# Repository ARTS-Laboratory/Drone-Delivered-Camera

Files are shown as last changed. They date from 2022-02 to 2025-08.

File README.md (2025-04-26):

# Drone-Delivered-Camera
A UAV deployable camera 

<p align="center">
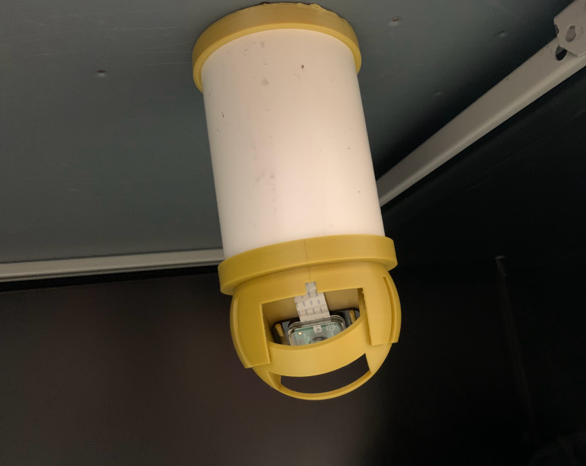
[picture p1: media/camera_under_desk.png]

</p>
<p align="center">
Figure 1: Camera Package installed underneath a structure.
</p>

## Licensing and Citation

[][cc-by-sa]

This work is licensed under a
[Creative Commons Attribution-ShareAlike 4.0 International License][cc-by-sa].

[cc-by-sa]: http://creativecommons.org/licenses/by-sa/4.0/
[cc-by-sa-image]: https://licensebuttons.net/l/by-sa/4.0/88x31.png
[cc-by-sa-shield]: https://img.shields.io/badge/License-CC%20BY--SA%204.0-lightgrey.svg

Cite as:

@Misc{ARTSLabDroneDeliveredCamera,     
  author = {{ARTS-L}ab},  
  howpublished = {GitHub},    
  title  = {Drone Delivered Camera},    
  groups = {{ARTS-L}ab},    
  url    = {https://github.com/ARTS-Laboratory/Drone-Delivered-Camera},   
}

<p align="center">
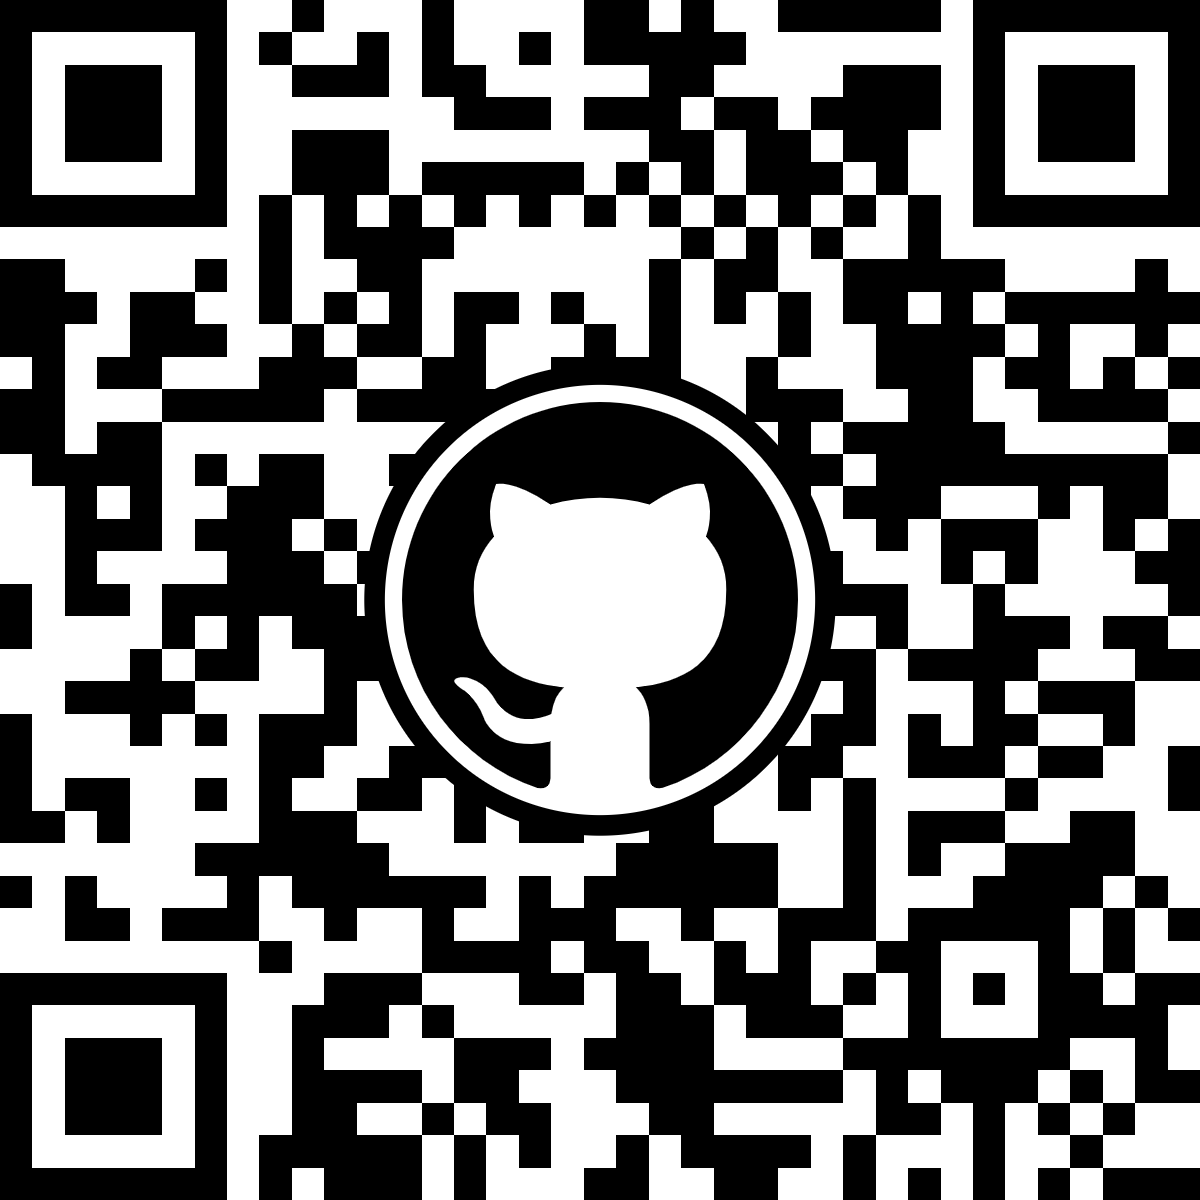
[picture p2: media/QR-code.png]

</p>
<p align="center">
QR code for repo.
</p>

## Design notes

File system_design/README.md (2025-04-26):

# System Design
The versions of the sensor package are all named after observatories.

## Palomar
....

## Rubin
....

## Lowell
....

## Keck
....

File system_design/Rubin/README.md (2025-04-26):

# Rubin

UAV deployable camera package for monitoring hydrology and performing edge computing. 
<p align="center">

</p>
<p align="center">
Figure 1: Camera Package installed underneath a structure.
</p>

## Modular Components
The major components of this package are:
1. Control Board (Raspberry Pi)
2. Camera (PiCam v2.1)
3. Electropermanent Magnet
4. Radio Chip (NRF)

## NRFCommunicate

NRFCommunicate wraps a basic NRF circuit-python package. The goal is to create a plug-and-play library not just for uploading data, but also for communication between sensor packages.

## V1
1.	Powered off battery (not battery monitoring)
1.	Begins program on startup
1.	Takes picture whenever it gets a signal from the NRF
1.	Images stored on a SD card on the PI (not sure how to extract data)
1.	Has the electro permanent magnet that can turn on and off with a signal from the NRF (need to see if we can integrates this with the controller from the gauge sensor)

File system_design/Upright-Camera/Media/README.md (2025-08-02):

File contains necessary pictures on any updated parts/software for the Fisheye Lens Upright Camera Package.

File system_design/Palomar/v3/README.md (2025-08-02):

File contains necessary information on any updated parts/software for the Palomar Camera Package.

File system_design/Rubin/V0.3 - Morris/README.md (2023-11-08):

# V0.3.0 -Morris
UAV deployable camera package for monitoring hydrology and performing edge computing.

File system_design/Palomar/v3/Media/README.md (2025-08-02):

File contains necessary Pictures on any updated parts/software for the Palomar Camera Package.

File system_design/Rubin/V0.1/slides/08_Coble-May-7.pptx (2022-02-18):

## MACHINE LEARNING DETECTION OF FOREST FIRES

Nile Coble Week 1 Review

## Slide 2

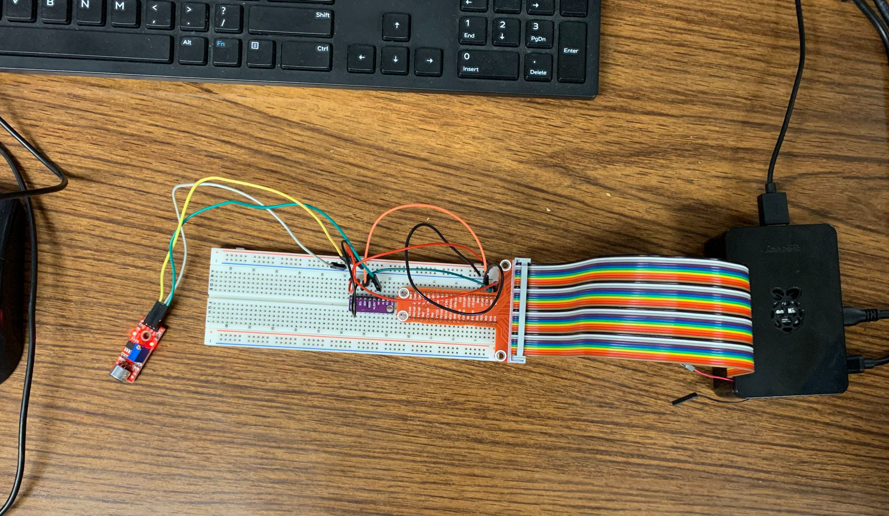
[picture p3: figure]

ADC ^

^ RPi pinout

<-- microphone

Raspberry Pi ^

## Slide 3

Current state
- Record for a given time and create a .wav file
Issues
- Aliased to below 430 Hz
- Small amount of unique mV values within range:
Min mV: 30448
Max mV: 31264
Range: 816
Unique values: 31

## THANK YOU

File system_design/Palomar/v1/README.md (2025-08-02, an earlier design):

Folder Contains necessary information regarding CAD Files, Software, and any other
items used in the construction of Palomar v1.

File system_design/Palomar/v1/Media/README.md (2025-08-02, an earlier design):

Pictures within this file showcase the first version of
the Palomar Camera Package, with a simple glued-on camera
that runs YOLOv11 through a RaspberryPi 4. Package was meant
to prototype a wireless package that could be dropped and
identify objects.

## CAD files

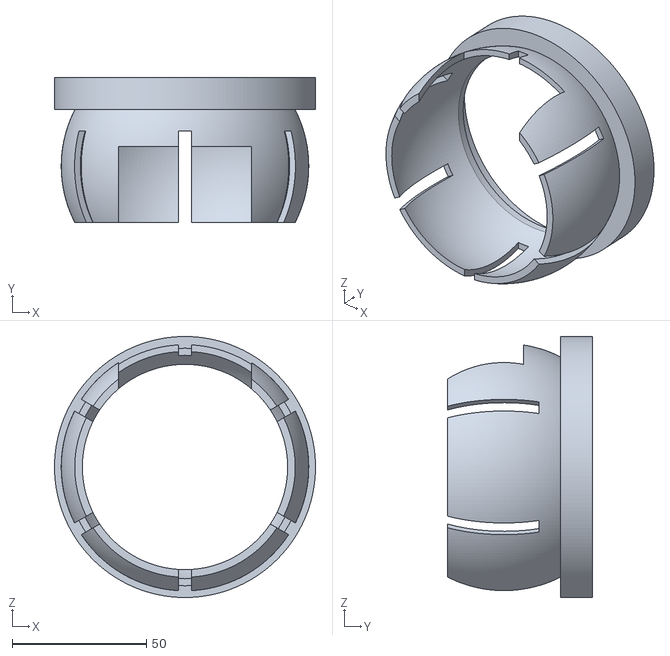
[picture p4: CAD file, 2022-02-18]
system_design/Rubin/V0.1/CAD/stl/bot-v2.stl
97.2 x 54.0 x 97.2

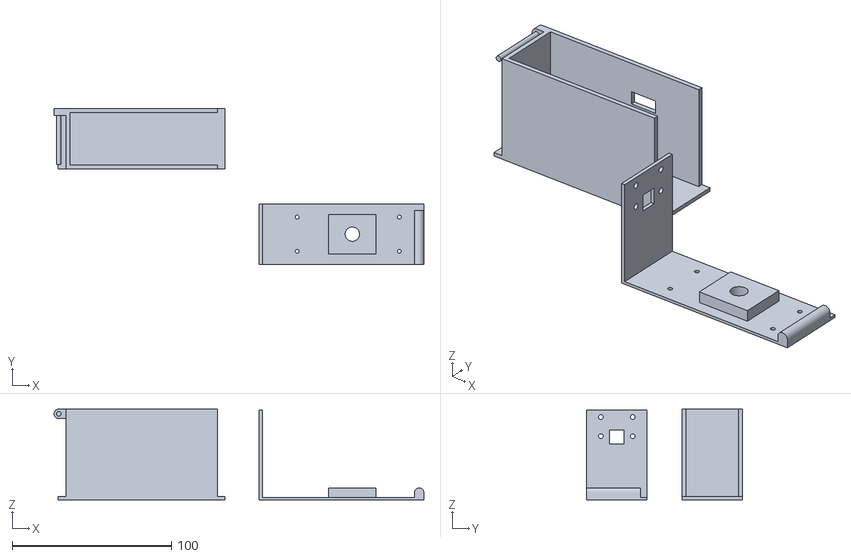
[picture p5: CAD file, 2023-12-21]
system_design/Rubin/V0.3 - Morris/Case Camera_.stl
232.3 x 97.9 x 57.0

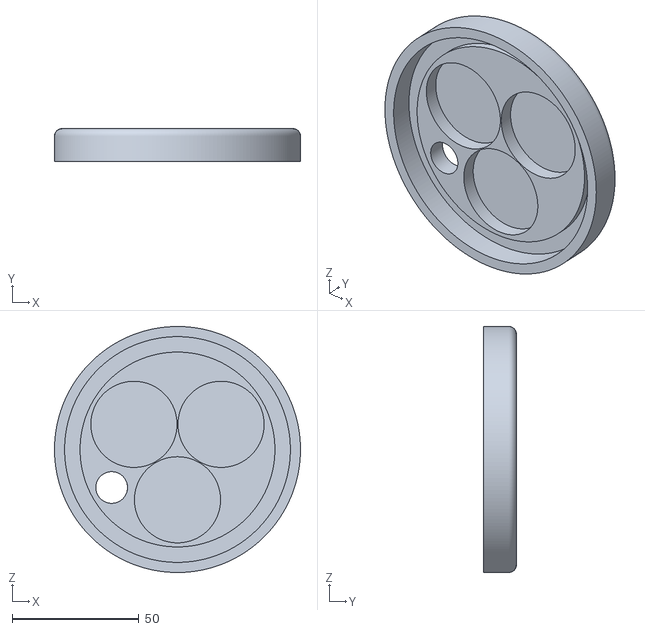
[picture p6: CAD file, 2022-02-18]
system_design/Rubin/V0.1/CAD/stl/lid-proto-v2.stl
97.1 x 13.0 x 97.1

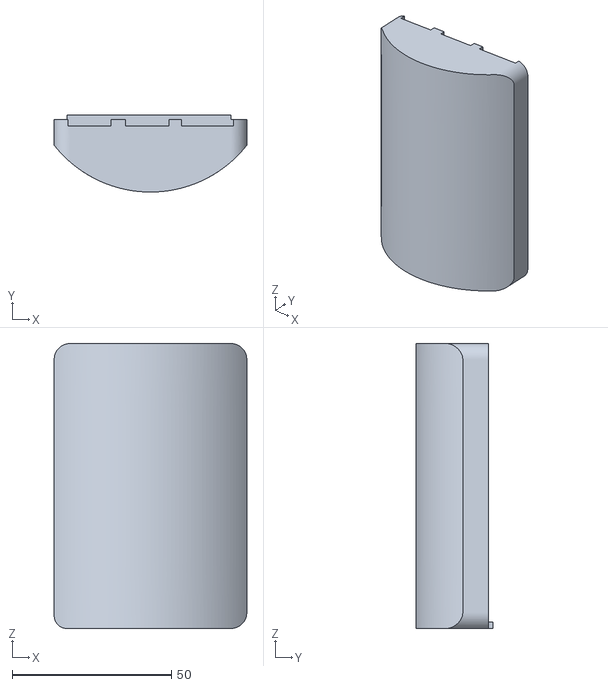
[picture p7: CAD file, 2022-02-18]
system_design/Rubin/V0.2 - Toth/CAD/stl/piholder-v5.stl
60.5 x 24.2 x 89.5

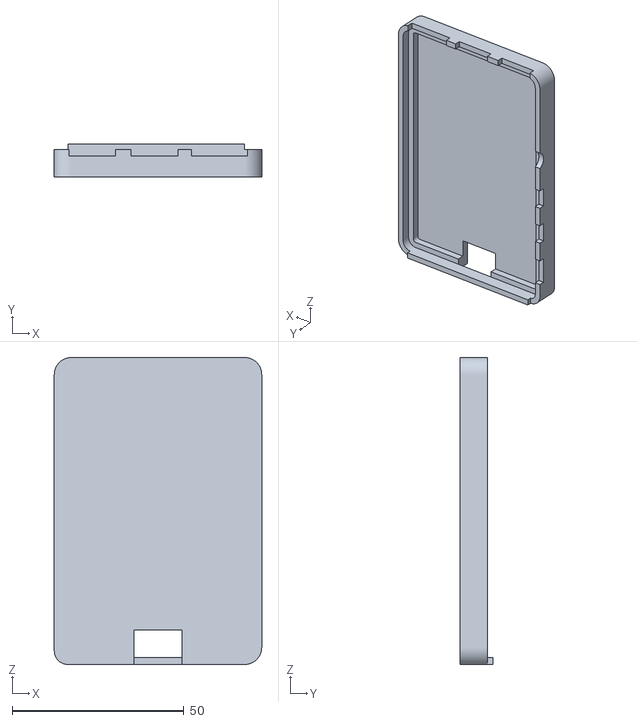
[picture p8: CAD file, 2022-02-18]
system_design/Rubin/V0.1/CAD/stl/piholder-proto-v4.stl
60.5 x 9.50 x 89.5

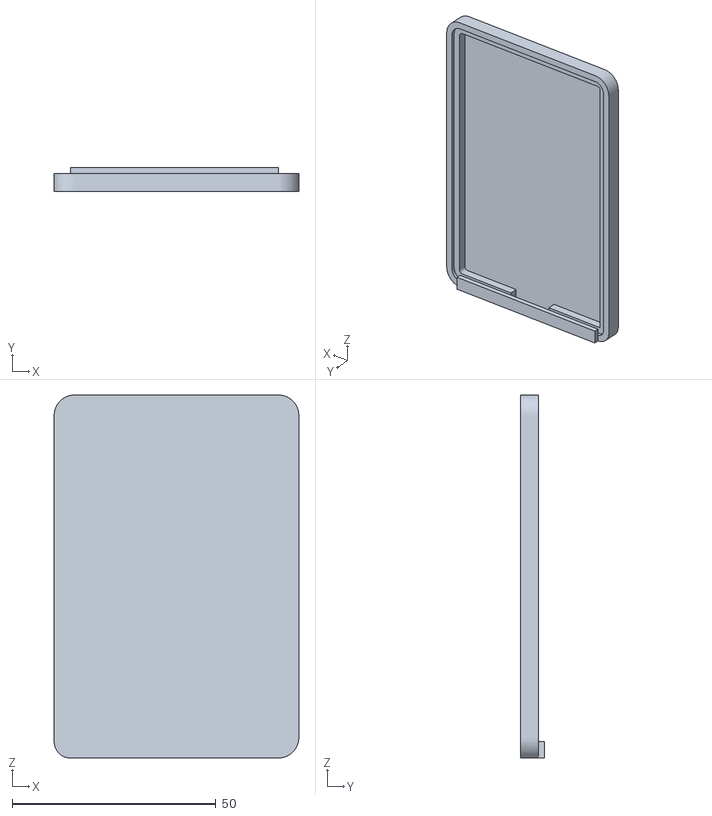
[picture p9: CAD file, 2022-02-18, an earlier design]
system_design/Rubin/V0.2 - Toth/CAD/stl/piholder-v1.stl
60.0 x 6.00 x 89.0

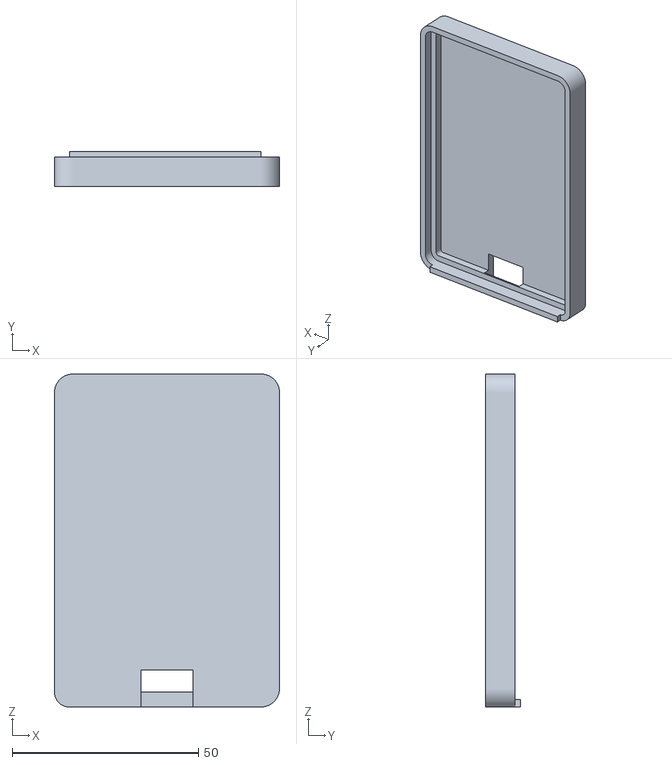
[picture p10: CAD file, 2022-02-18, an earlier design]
system_design/Rubin/V0.2 - Toth/CAD/stl/piholder-proto-v3.stl
60.5 x 9.50 x 89.5

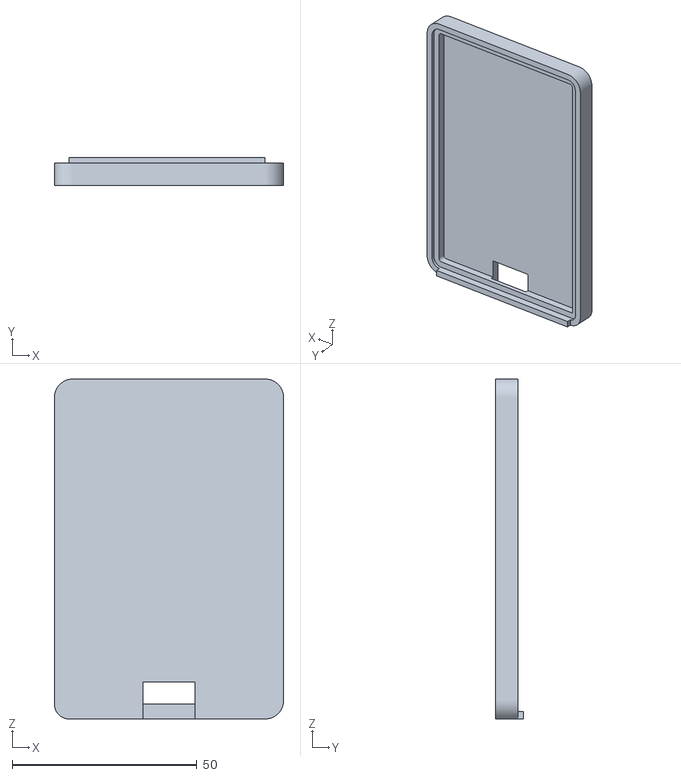
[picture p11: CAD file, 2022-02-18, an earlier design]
system_design/Rubin/V0.2 - Toth/CAD/stl/piholder-v2.stl
62.0 x 7.50 x 92.0

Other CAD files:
system_design/Rubin/V0.1/CAD/stl/lid-v1.stl
system_design/Rubin/V0.2 - Toth/CAD/stl/lid-v1.stl
system_design/Rubin/V0.2 - Toth/CAD/stl/bot-v1.stl
system_design/Rubin/V0.1/CAD/stl/lid-proto-v1.stl
system_design/Palomar/v1/PalomarBaseTop.ipt
system_design/Palomar/v1/PalomarRasPiCoverBottom1.ipt
system_design/Palomar/v1/PalomarRasPiCoverTop.ipt
system_design/Palomar/v2/PalomarRasPiCoverBottom.ipt
system_design/Palomar/v3/PalomarFlirAdapter.ipt
system_design/Rubin/V0.1/CAD/ipt/bot-v1.ipt
system_design/Rubin/V0.1/CAD/ipt/bot-v2.ipt
system_design/Rubin/V0.1/CAD/ipt/box-v1.ipt
system_design/Rubin/V0.1/CAD/ipt/lid-proto-v1.ipt
system_design/Rubin/V0.1/CAD/ipt/lid-proto-v2.ipt
system_design/Rubin/V0.1/CAD/ipt/lid-v1.ipt
system_design/Rubin/V0.1/CAD/ipt/piholder-proto-v3.ipt
system_design/Rubin/V0.1/CAD/ipt/piholder-proto-v4.ipt
system_design/Rubin/V0.1/CAD/ipt/piholder-proto-v5.ipt
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

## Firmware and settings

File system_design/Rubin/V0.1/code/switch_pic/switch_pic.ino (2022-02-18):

// now working towards having the rPi and Arduino specifications working together. this sends TESTMSG once every 5 seconds, and turns on an led at the same time.
// the pi and arduino leds should blink in syncronicity.
#include<SPI.h>                   // spi library for connecting nrf
#include <Wire.h>                 // i2c libary fro 16x2 lcd display
#include<RF24.h>                  // nrf library


RF24 radio(9, 10) ;  // ce, csn pins
static byte signs[2][7] = {{'T', 'A', 'K', 'E', 'P', 'I', 'C'},
                           {'T', 'E', 'S', 'T', 'M', 'S', 'G'}}; //TAKEPIC, TESTMSG
int prevVal;
int count = 0;
int startTime;
void setup(void) {
//  SPI.begin();
//  SPI.setBitOrder(MSBFIRST);
  radio.begin(); // start radio at ce csn pin 9 and 10
  Serial.begin(9600) ; // start serial monitor baud rate
  Serial.println("Starting.. Setting Up.. Radio on.."); // debug message
  radio.setPALevel(RF24_PA_MIN); // set power level. one of RF24_PA_MIN, RF24_PA_LOW, RF24_PA_HIGH, RF24_PA_MAX
  radio.setChannel(76); // set chanel at 76
  //const uint64_t pipes[2] = {0x43414d5241,0x5249564552};
  uint8_t pipes[][6] = {"CAMRA", "RIVER"};
  radio.openReadingPipe(0, pipes[0]); // start reading pipe
  radio.openWritingPipe(pipes[1]);
  radio.setPayloadSize(16);
  radio.powerUp();

  pinMode(8, OUTPUT);
  pinMode(7, INPUT);
  prevVal = digitalRead(7);
}
void sendSign(int index) {
  radio.write(&signs[index], 7);
}
void loop(void) {
  int currentVal = digitalRead(7);
  int currentTime = millis();
  if(digitalRead(7) == 1 && prevVal == 0) {
    digitalWrite(8, 1);
    startTime = currentTime;
    sendSign(1);
    prevVal = 1;
    Serial.println("sending TESTMSG on switch");
  }
  if(digitalRead(7) == 0 && prevVal == 1) {
    digitalWrite(8,0);
    prevVal = 0;
  }
  if(currentVal == 1 && (currentTime - startTime) > 1000) {
    sendSign(0);
    startTime = currentTime;
    Serial.println("sending TAKEPIC after second");
  }
}

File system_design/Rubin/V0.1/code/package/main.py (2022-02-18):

"""
run this on start-up by entering into terminal:
sudo nano /etc/rc.local
and add:
python3 /home/pi/Camera/main.py &
exit 0
currently supported signs:
TESTMSG, TAKEPIC, DEEPLOY, SUICIDE
"""
import argparse
import digitalio
import board
from nrf_com.nrf_communicate import NRF_communicate, Sign
import time
from picamera import PiCamera
from camsign import CamSign

parser = argparse.ArgumentParser()
parser.add_argument("--testmode", help="set to run test mode",
                    action="store_true")
args = parser.parse_args()

def test_msg(led):
    print("testing, TESTING, 1, 2, 3...")
    led.value = True
    time.sleep(1)
    led.value = False
#this flips the magnet state, thus working for DEEPLOY and SUICIDE
def flip_mag(mag):
    mag.value = True
    time.sleep(.2)
    mag.value = False

ce = digitalio.DigitalInOut(board.CE0)
csn = digitalio.DigitalInOut(board.D25)
led = digitalio.DigitalInOut(board.D14)
led.direction = digitalio.Direction.OUTPUT
mag = digitalio.DigitalInOut(board.D15)
mag.direction = digitalio.Direction.OUTPUT

address = [b"CAMRA", b"RIVER"]

test_sign = Sign("TESTMSG", act_on_sign=True, funct=test_msg, args=[led])
deploy_sign = Sign("DEEPLOY", act_on_sign=True, funct=flip_mag, args=[mag])
sui_sign = Sign("SUICIDE", act_on_sign=True, funct=flip_mag, args=[mag])
class CamSign(Sign):
    def __init__(self):
        from picamera import PiCamera
        self.count = 0
        self.name = "TAKEPIC"
        self.camera = PiCamera()
        self.camera.resolution = ((3280, 2464),
                                  (1024, 768),
                                  (640, 480))[0]
        self.camera.rotation = (0, 90, 180, 270)[2]
        
    def on_sign(self, semisig = '---'):
        stream=open("./pics/img{}.png".format(self.count), 'wb')
        self.camera.capture(stream, format='jpeg')
        stream.close()
        self.count += 1
        
cam_sign = CamSign()

test_mode = args.testmode
while(test_mode):
    test_sign.on_sign()
    time.sleep(2)
    cam_sign.on_sign()
    time.sleep(8)
    print("test sequence repeat loop")

nrf_com = NRF_communicate(ce, csn, address[0], address[1], \
                signs=(test_sign, cam_sign, deploy_sign, sui_sign), 
                encode = False)
print("waiting for sign...")
while(True):
    sign = nrf_com.block_until_sign()
    if(sign == "TAKEPIC"):
        
    print("sign found")

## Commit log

2022-02-18 first push with Nile's stuff
    [bot-v1.ipt, bot-v1.stl, bot-v2.ipt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]
2022-02-18 added v1.1
    [bot-v1.ipt, bot-v1.stl, bot-v2.ipt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]
2023-11-08 Clean up for V0.3 Morris
    [bot-v1.ipt, bot-v1.stl, bot-v2.ipt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]
2025-04-26 re-organized the repo
    [Case Camera_.stl, bot-v1.ipt, bot-v1.stl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]
2025-05-23 Add files via upload
    Design Features:
    Fixed Camera Mount within protective sphere on top
    PLA 3D printed base and top mount
    4-inch PVC pipe to house hardware
    70% infill on bottom piece and 50% on top piece
    Fixed mount would satisfy testing and early concept building, but a new camera mount would soon need to replace it.
    Componants:
    Arducam 12MP IMX708 102 for Raspberry Pi
    PiSugar Raspberry Pi Battery with Power Manager
    Raspberry Pi 4
    64 GB SD Card
    Experimented with different cameras and settled on a PiCam to limit the amount of space needed on top of the package and inside the housing.
    Processor in Raspberry Pi 4 extremely slow in testing; will need an upgraded version soon.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
2025-05-23 Add files via upload
    Pivot Camera Mount within protective sphere on top.
    PLA 3D printed base and top mount.
    4-inch PVC pipe to house hardware.
    Mounting Screws and Standoffs repurposed to dig into the inner walls of protective sphere.
    Pivoting Mount allows 180 degrees of visibility, adjustment anywhere on the space allowed for the camera.
    No risk of wear to the pivot.
    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
